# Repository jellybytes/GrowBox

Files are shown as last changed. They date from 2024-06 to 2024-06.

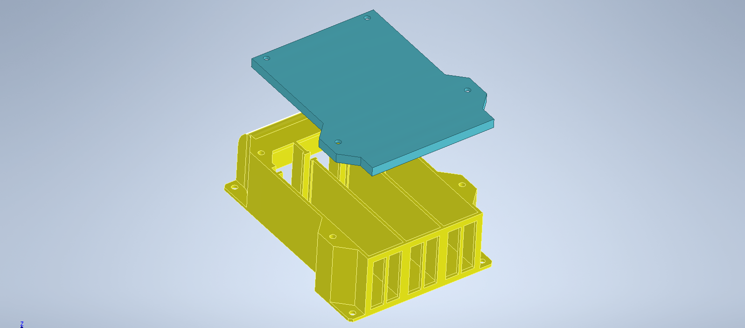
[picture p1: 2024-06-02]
hardware/CarbonFilter/docs/assembly.png

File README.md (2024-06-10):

# GrowBox
Growbox software raspberry pi. Read temperature sensors, control fans and lights.

# Temperature Sensors
2 x Bosch BME280
i2C Adresses 0x76 / 0x77 -> connect solder bridge + cut default bridge!!

**Bring Up:**
- enable i2c raspberry pi
- `sudo apt-get install libi2c-dev`
- `sudo apt install i2c-tools`
- `i2cdetect -y 1` on raspi command line to verify

default baudrate 100Kbps -> increase with `gpio load i2c 400` to 400Kbps

# Fan Speed Control
- `gpio readall` to print wPi <-> BCM pin mapping

**PWM Pins**
| BCM | PWM |
|---|---|
| 12 | PWM0 |
| 18 | PWM0 |
| 13 | PWM1 |
| 19 | PWM1 |

Use BCM pins `12` and `13` -> wPi pins `GPIO26` and `GPIO23`

# Display
SSD1306 based 128x64 pixel OLED screen. I2c address `0x3c`

# Button / Light Control
GPIO21 (wPi) -> BCM 5
GPIO22 (wPi) -> BCM 6

# Dependencies
sudo apt install -y mosquitto-dev mosquitto-clients
wiringPi..

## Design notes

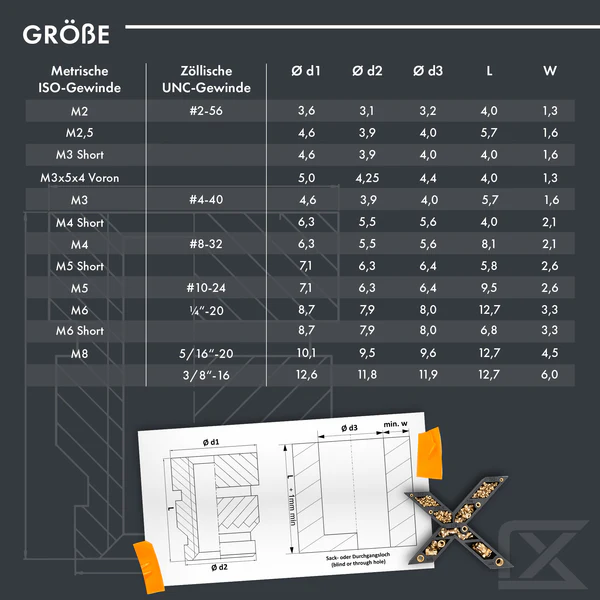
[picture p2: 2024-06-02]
hardware/CarbonFilter/docs/ThreadedNuts.jpg

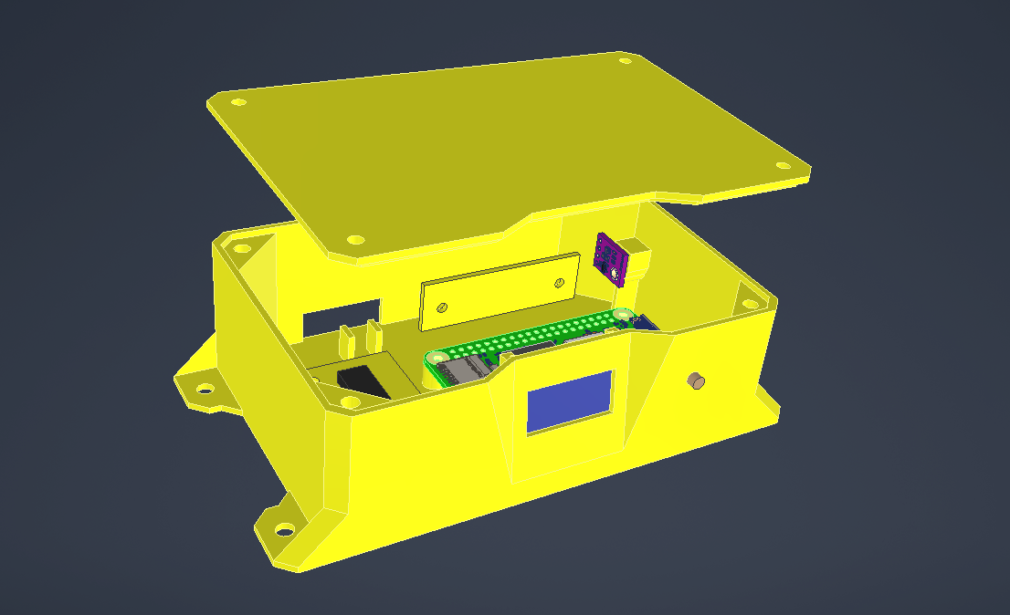
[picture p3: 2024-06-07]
hardware/MasterCtrlCase/MasterCtrlCase.png

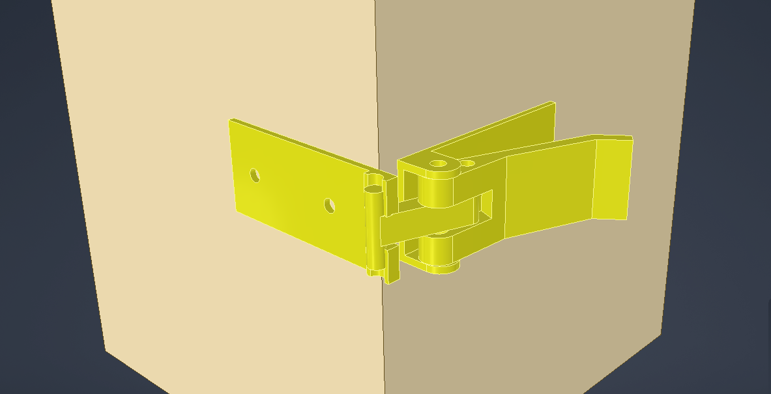
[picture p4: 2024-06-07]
hardware/ToggleLatch/ToggleLatch.png

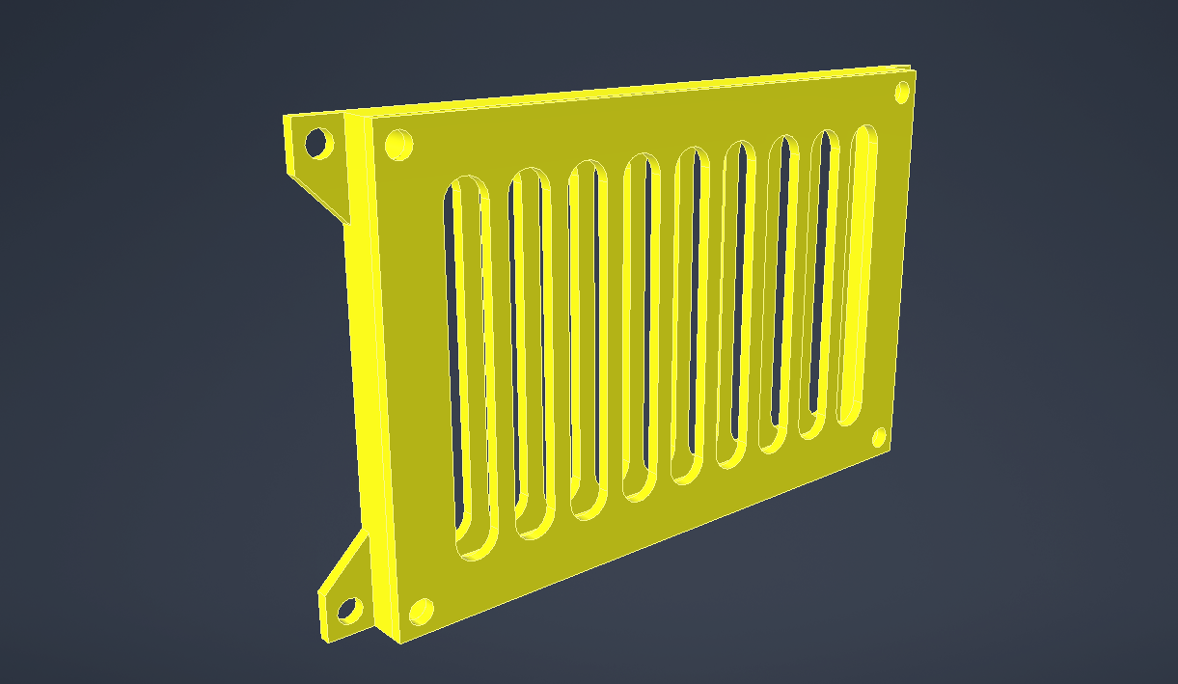
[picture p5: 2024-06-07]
hardware/IntakeFilter/IntakeFilter.png

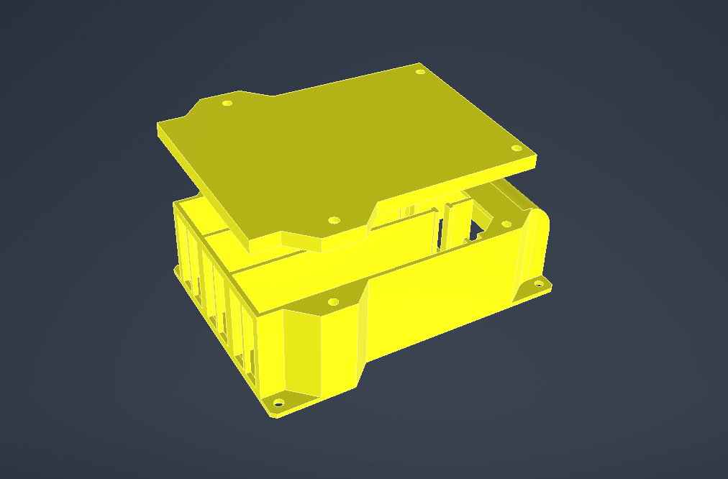
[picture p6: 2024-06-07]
hardware/CarbonFilter/CarbonFilter.png

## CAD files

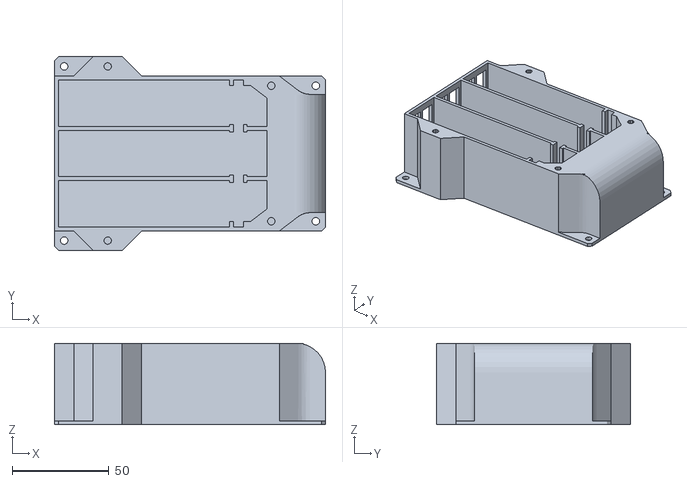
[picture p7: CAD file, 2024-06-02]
hardware/CarbonFilter/stl/MainBody.stl
140.0 x 100.0 x 42.0

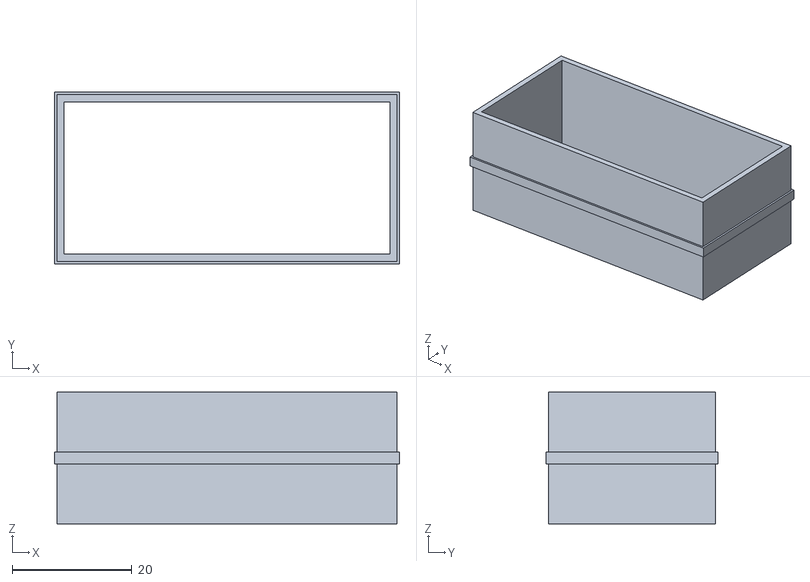
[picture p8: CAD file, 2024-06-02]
hardware/CarbonFilter/stl/Connector.stl
57.7 x 28.7 x 22.0

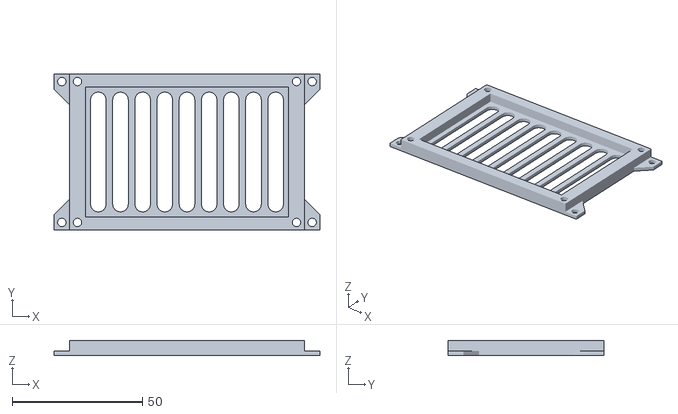
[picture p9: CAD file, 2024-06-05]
hardware/IntakeFilter/stl/IntakeFilterTop.stl
102.0 x 60.0 x 5.60

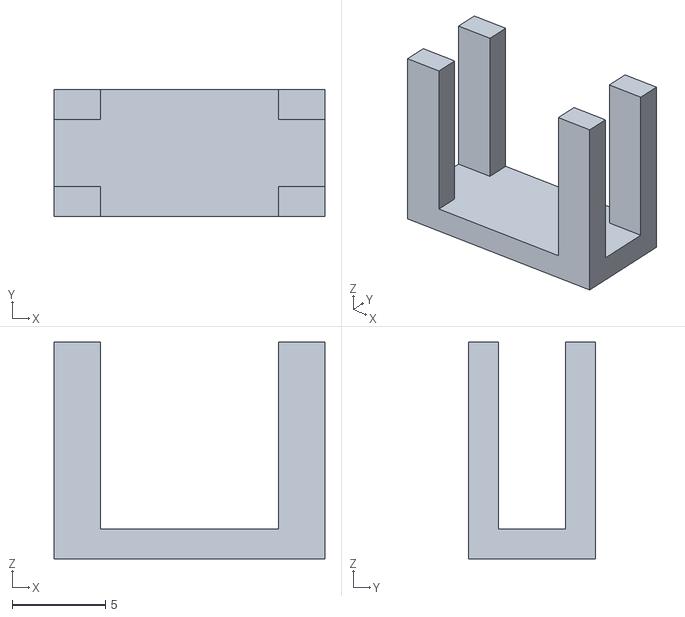
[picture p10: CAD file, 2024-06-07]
hardware/MasterCtrlCase/stl/ButtonLock.stl
14.5 x 6.80 x 11.6

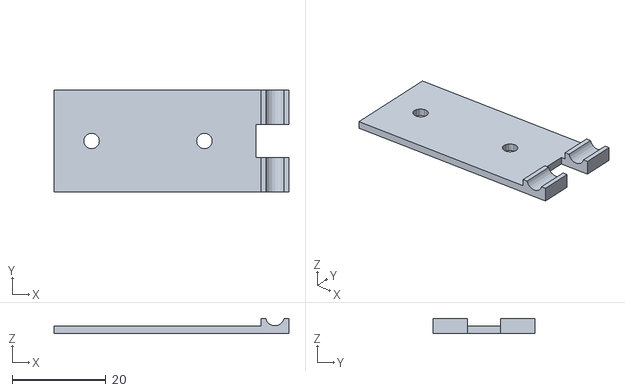
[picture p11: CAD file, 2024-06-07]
hardware/ToggleLatch/stl/Counter.stl
50.0 x 21.8 x 3.10

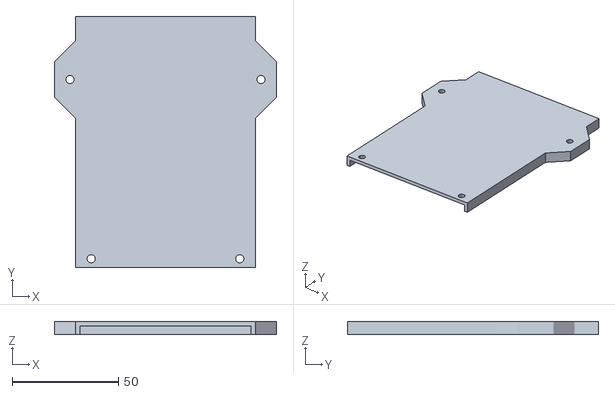
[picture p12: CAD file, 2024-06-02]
hardware/CarbonFilter/stl/Cover.stl
104.6 x 118.5 x 6.00

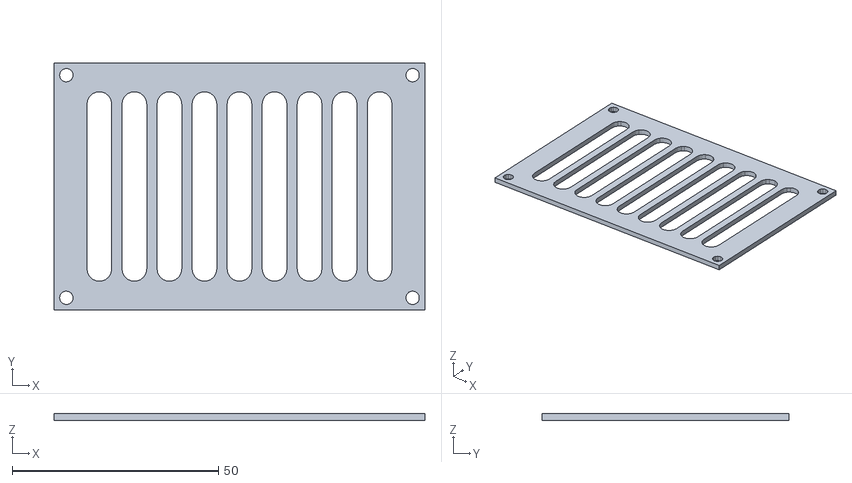
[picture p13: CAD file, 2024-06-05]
hardware/IntakeFilter/stl/IntakeFilterBottom.stl
90.0 x 60.0 x 1.60

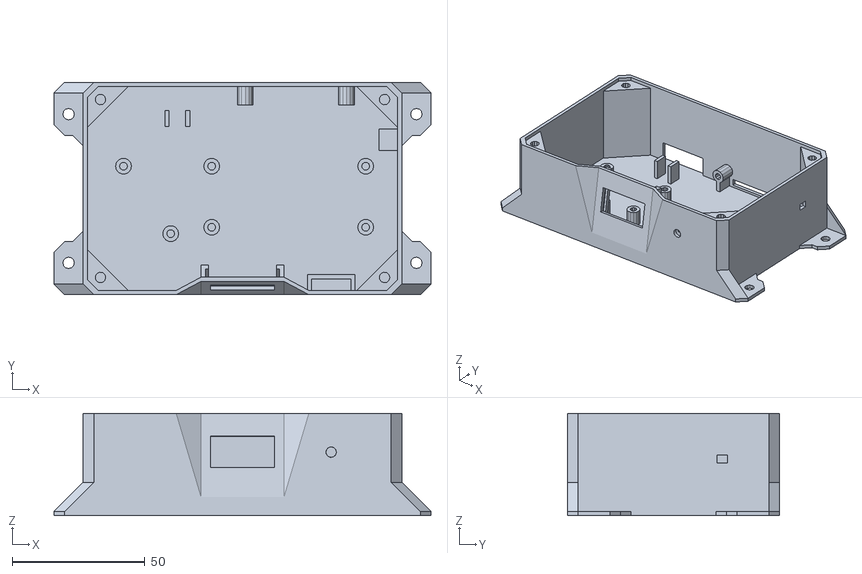
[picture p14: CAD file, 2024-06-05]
hardware/MasterCtrlCase/stl/BasePlate.stl
142.0 x 80.0 x 38.6

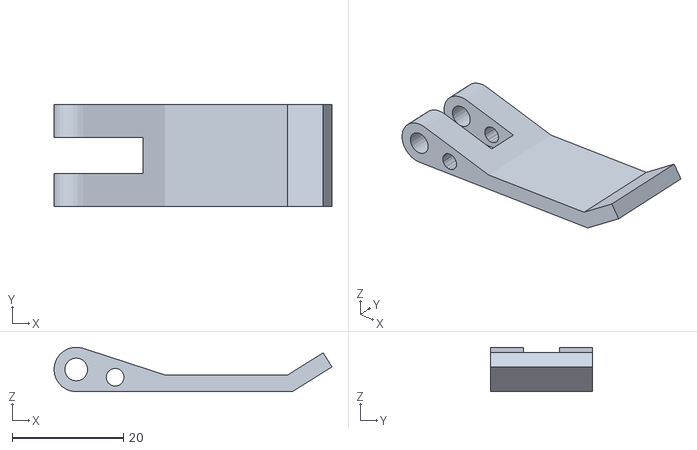
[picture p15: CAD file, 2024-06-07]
hardware/ToggleLatch/stl/Lever.stl
50.0 x 18.4 x 7.99

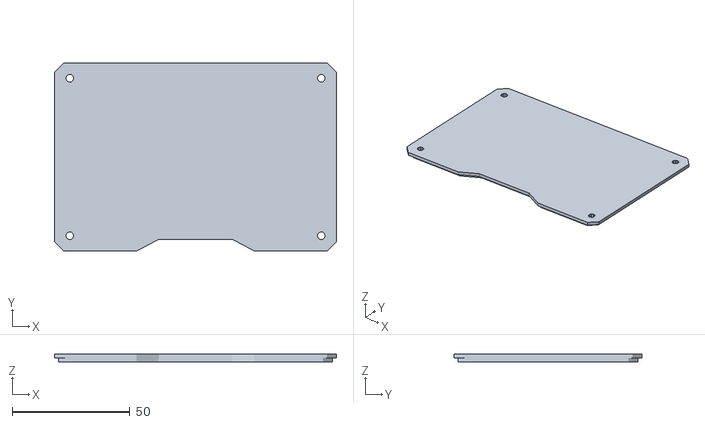
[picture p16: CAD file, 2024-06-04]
hardware/MasterCtrlCase/stl/Top.stl
120.0 x 80.0 x 3.20

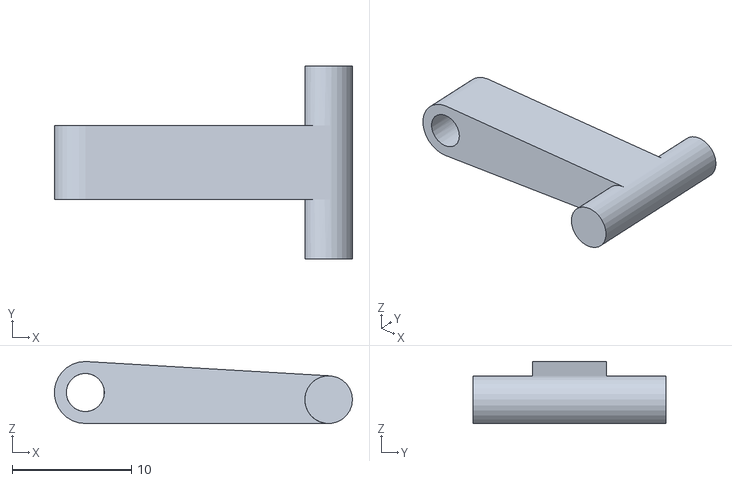
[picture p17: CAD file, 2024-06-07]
hardware/ToggleLatch/stl/Latch.stl
25.0 x 16.2 x 5.20

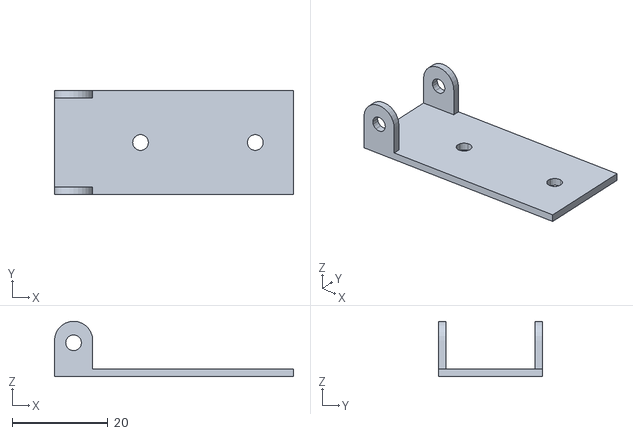
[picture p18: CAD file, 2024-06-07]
hardware/ToggleLatch/stl/Base.stl
50.0 x 21.8 x 11.6

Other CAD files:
hardware/CarbonFilter/Connector.ipt
hardware/CarbonFilter/Cover.ipt
hardware/CarbonFilter/Filter.iam
hardware/CarbonFilter/MainBody.ipt
hardware/IntakeFilter/IntakeFilter.iam
hardware/IntakeFilter/IntakeFilterBottom.ipt
hardware/IntakeFilter/IntakeFilterTop.ipt
hardware/MasterCtrlCase/293D.ipt
hardware/MasterCtrlCase/BasePlate.ipt
hardware/MasterCtrlCase/DeviceConnector.ipt
hardware/MasterCtrlCase/MasterCtrlCase.iam
hardware/MasterCtrlCase/Switch.ipt
hardware/MasterCtrlCase/Top.ipt
hardware/MasterCtrlCase/step/GY-BME280/GY-BME280.ipt
hardware/MasterCtrlCase/step/Raspberry Pi Zero 2 W/54548-2271, 22 Pin FPC Connector, Raspberry Pi Zero 2 W.ipt
hardware/MasterCtrlCase/step/Raspberry Pi Zero 2 W/Crystal Resonator, Raspberry Pi Zero 2 W.ipt
hardware/MasterCtrlCase/step/Raspberry Pi Zero 2 W/Diode, Schottky, Raspberry Pi Zero 2 W.ipt
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

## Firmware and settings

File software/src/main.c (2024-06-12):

#include "main.h"

#include <stdio.h>
#include <stdlib.h>
#include <string.h>
#include <stdint.h>

#include <wiringPi.h>
#include <wiringPiI2C.h>

#include "mqtt_utils.h"
#include "cJSON.h"
#include "bme280.h"
#include "ssd1306_i2c.h"


// temperature sensors
#define BME280_IN_ADDR 	0x76
#define BME280_EX_ADDR 0x77

BME280 bme280_in = {0};
BME280 bme280_ex = {0};

int init_env_sense();
void update_env_sense();

// fan utility
FAN_CTRL fan_one;
FAN_CTRL fan_two;

int init_fan_CTRL();
void update_fan_state(char *state);
void update_fan_speed(char *speed);
void fan_CTRL(FAN_CTRL *ctrl);

// oled display
void init_OLED();
void update_OLED();
bool disp_on = false;
uint8_t disp_on_cycles = 0;

#define BUTTON_PIN 22
int init_button();
void button_callback();

struct mosquitto *mosq;

int main()
{
	mosq = mosquitto_new(NULL, true, NULL);
	if(mosq == NULL){
		fprintf(stderr, "Error: Out of memory.\n");
		return EXIT_FAILURE;
	}

	if (init_mqtt(mosq) != EXIT_SUCCESS)
	{
		fprintf(stderr, "Error: Init mqtt connection failed.\n");
		return EXIT_FAILURE;
	}

	if (init_fan_CTRL() != EXIT_SUCCESS)
	{
		fprintf(stderr, "Error: Init PWM for fan control.\n");
		return EXIT_FAILURE;
	}
	update_fan_state("false");
	update_fan_speed("50");

	if (init_env_sense() != EXIT_SUCCESS)
	{
		fprintf(stderr, "Error: Init environment sensors\n");
		return EXIT_FAILURE;
	}
	update_env_sense();

	init_OLED();
	update_OLED();

	init_button();

	// blocking while loop, handles mqtt reconnect and
	// calls on_message if subscribed topic inc
	mosquitto_loop_forever(mosq, -1, 1);

	mosquitto_lib_cleanup();
	return 0;
}

void on_message(struct mosquitto *mosq, void *obj, const struct mosquitto_message *msg)
{
	UNUSED(obj);
	UNUSED(mosq);
	// fan state
	if (strcmp(msg->topic, "gb_ex_fan/on/set") == 0) update_fan_state((char *)msg->payload);
	// fan speed
	else if (strcmp(msg->topic, "gb_ex_fan/speed/percentage") == 0) update_fan_speed((char *)msg->payload);
	// bme280 environment sensor
	else if (strcmp(msg->topic, "gb_env_sense/update") == 0) update_env_sense();
}

int init_fan_CTRL()
{
	// initialise wiringPi with wPi numbering
	if (wiringPiSetup() == -1) 
	{
		printf("Error: Setting up wiringPi.\n");
		return EXIT_FAILURE;
	}

	fan_one.pwm_pin = 26;
	fan_one.state = false;
	fan_one.speed = 10; // range 10 - 180

	fan_two.pwm_pin = 23;
	fan_two.state = false;
	fan_two.speed = 10;

	// motor control PWM setup
	// fixed period for all Duty cycles
	pinMode(fan_one.pwm_pin, PWM_OUTPUT);
	pinMode(fan_two.pwm_pin, PWM_OUTPUT);

	pwmSetMode(PWM_MODE_MS);
	// clock divider 19.2 MHz / x
	// pwmFreq = 19.2e6 / clkDiv / range
	pwmSetClock(5);
	pwmSetRange(192);

	// set fans off
	fan_CTRL(&fan_one);
	fan_CTRL(&fan_two);
	return EXIT_SUCCESS;
}

int init_env_sense()
{
    // holds calibration and values after read
    bme280_in.fd = wiringPiI2CSetup(BME280_IN_ADDR);
    if(bme280_in.fd < 0) {
    	printf("Error: Temperature sensor not found");
		return EXIT_FAILURE;
	}
    setupBME280(&bme280_in);

    bme280_ex.fd = wiringPiI2CSetup(BME280_EX_ADDR);
    if(bme280_ex.fd < 0) {
    	printf("Error: Temperature sensor not found");
		return EXIT_FAILURE;
    }
    setupBME280(&bme280_ex);

	return EXIT_SUCCESS;
}

void init_OLED()
{
	ssd1306_begin(SSD1306_SWITCHCAPVCC, SSD1306_I2C_ADDRESS);
	ssd1306_setTextSize(3);
}

int init_button()
{
	if (wiringPiISR(BUTTON_PIN, INT_EDGE_FALLING, &button_callback) < 0)
	{
        printf("Error: Unable to setup ISR.\n");
		return EXIT_FAILURE; // 27343
	}
	return EXIT_SUCCESS;
}

void button_callback()
{
	uint8_t edge = 0b10000000;
	uint8_t stream = 0b11111111;
	for(int i = 0; i < 16; i++)
	{
	    stream <<= 1;
	    stream |= digitalRead(BUTTON_PIN);

	    if (stream == edge)
	    {
			// printf("button pressed!\n");
			disp_on = true;
			update_OLED();
	        break;
	    }
	   delay(3);
	}
}

void update_fan_state(char *state)
{
	if (!strcmp(state, "true"))
	{
		// printf("fan on: %s\n", state);
		fan_one.state = true;
		fan_CTRL(&fan_one);

		mqtt_publish(mosq, "gb_ex_fan/on/state", state);
	}
	else if (!strcmp(state, "false"))
	{
		// printf("fan off: %s\n", state);
		fan_one.state = false;
		fan_CTRL(&fan_one);

		mqtt_publish(mosq, "gb_ex_fan/on/state", state);
	}
}

void update_fan_speed(char *speed)
{
	// printf("fan speed: %s\n", speed);
	fan_one.speed = atoi(speed);
	fan_CTRL(&fan_one);

	mqtt_publish(mosq, "gb_ex_fan/speed/percentage_state", speed);
}

void fan_CTRL(FAN_CTRL *ctrl)
{
	if (ctrl->state == false) {
		pwmWrite(ctrl->pwm_pin, 0);
	}
	else if (ctrl->state == true)
	{
		pwmWrite(ctrl->pwm_pin, ctrl->speed);
	}
}

void update_env_sense()
{
    readBME280(&bme280_in);
    // printf("temperature: %s °C\n", bme280_in.temperature);
    // printf("humidity: %s %%\n", bme280_in.humidity);
    readBME280(&bme280_ex);
    // printf("temperature: %s °C\n", bme280_ex.temperature);
    // printf("humidity: %s %%\n", bme280_ex.humidity);

	cJSON *root = NULL;
	const char *env_data[4] = {	bme280_ex.temperature, bme280_ex.humidity, 
								bme280_in.temperature, bme280_in.humidity };
	root = cJSON_CreateStringArray(env_data,4);
	char *payload = cJSON_Print(root);
	cJSON_Delete(root);

	mqtt_publish(mosq, "gb_env_sense/data", payload);

	if (disp_on == true && disp_on_cycles < 2) disp_on_cycles++;
	if (disp_on == true && disp_on_cycles >= 2)
	{
		disp_on = false;
		disp_on_cycles = 0;
	}
	update_OLED();
	update_OLED();
}

void update_OLED()
{
	if (disp_on == false)
	{
		ssd1306_clearDisplay();
		ssd1306_display(); // needed
	}
	else
	{
		ssd1306_clearDisplay();
		char print_buf[16] = {0};
		sprintf(print_buf, "%s C ", bme280_in.temperature);
		ssd1306_drawString(print_buf);

		char print_buf1[16] = {0};
 		sprintf(print_buf1, "%s   %%\n", bme280_in.humidity);
		ssd1306_drawString(print_buf1);

		ssd1306_display();
	}
}

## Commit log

2024-06-02 Added carbon filter design files
    [Cover.0005.ipt, Cover.ipt, Cover.stl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]
2024-06-02 First test BME280 temperature sensors
2024-06-02 Added OLED ssd1306 driver
2024-06-02 Print BME280 data OLED display
2024-06-02 Added fan to filter connector
    [Connector.ipt, Connector.stl]
2024-06-03 Designed case for main control electronics
    [293D.ipt, 54548-2271, 22 Pin FPC Connector, Raspberry Pi Zero 2 W.ipt, 662k - XC6206P182MR-G_1.ipt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]
2024-06-04 Added mounting holes MasterCtrlCase
    [BasePlate.0026.ipt, BasePlate.0044.ipt, BasePlate.ipt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]
2024-06-04 Added top cover MasterCtrlBox
    [BasePlate.0044.ipt, BasePlate.ipt, BasePlate.stl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]
2024-06-04 First PWM motor control test
2024-06-04 Stripped ssd1306 driver to needed functions only
2024-06-04 All devices working
2024-06-05 Added mounts MasterCtrlCase
    [BasePlate.ipt, BasePlate.stl, MasterCtrlCase.iam]
2024-06-05 Designed intake filter grow box
    [Connector.ipt, Connector.stl, Cover.0005.ipt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]
2024-06-05 Designed toggle latch for grow box
    [Base.ipt, Corner.ipt, Counter.ipt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]
2024-06-07 Finished 3D design
    [Base.stl, ButtonLock.ipt, ButtonLock.stl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]
2024-06-10 Implemented fan control from home assistant
2024-06-10 Update environment sensor data
2024-06-10 Send temperature values back mqtt
2024-06-12 Fixed no new env sense data bug due to missing conversion
    [main.c]
